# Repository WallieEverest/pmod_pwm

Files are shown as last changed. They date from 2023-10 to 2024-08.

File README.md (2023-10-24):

# Overview

This circuit is a PWM audio filter for the TT04 ChipTune project.
ChipTune replicates the Audio Processing Unit (APU) of vintage video games.
Separate PWM outputs are provided for each sound engine, allowing NES game music to be externally mixed into stereo or surround sound.
Resistor values will be tailored for balancing channel volume.

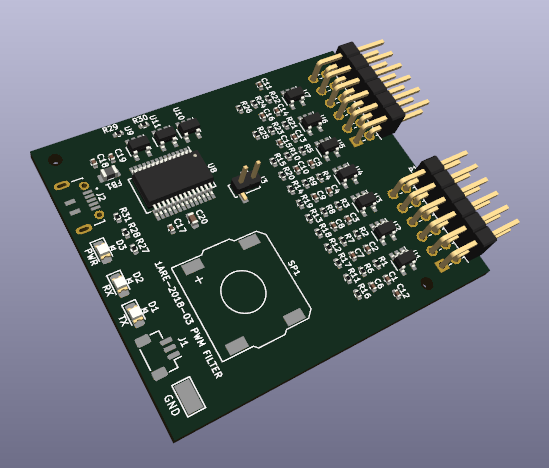
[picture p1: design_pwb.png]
Top Level Drawing


The primary interface is PMOD connectors to the TT04 Breakout Board. Final layout is pending assignment of all three PMOD connectors.

Based on data from:
- https://github.com/WallieEverest/tt04

## Interface

- UI_IN PMOD
- UO_OUT PMOD
- UIO PMOD (unused)
- USB-B for serial UART control of the Tiny Tapeout project
- JST 3-pin connector for low-level stereo preamp
- Onboard speaker for demonstrations

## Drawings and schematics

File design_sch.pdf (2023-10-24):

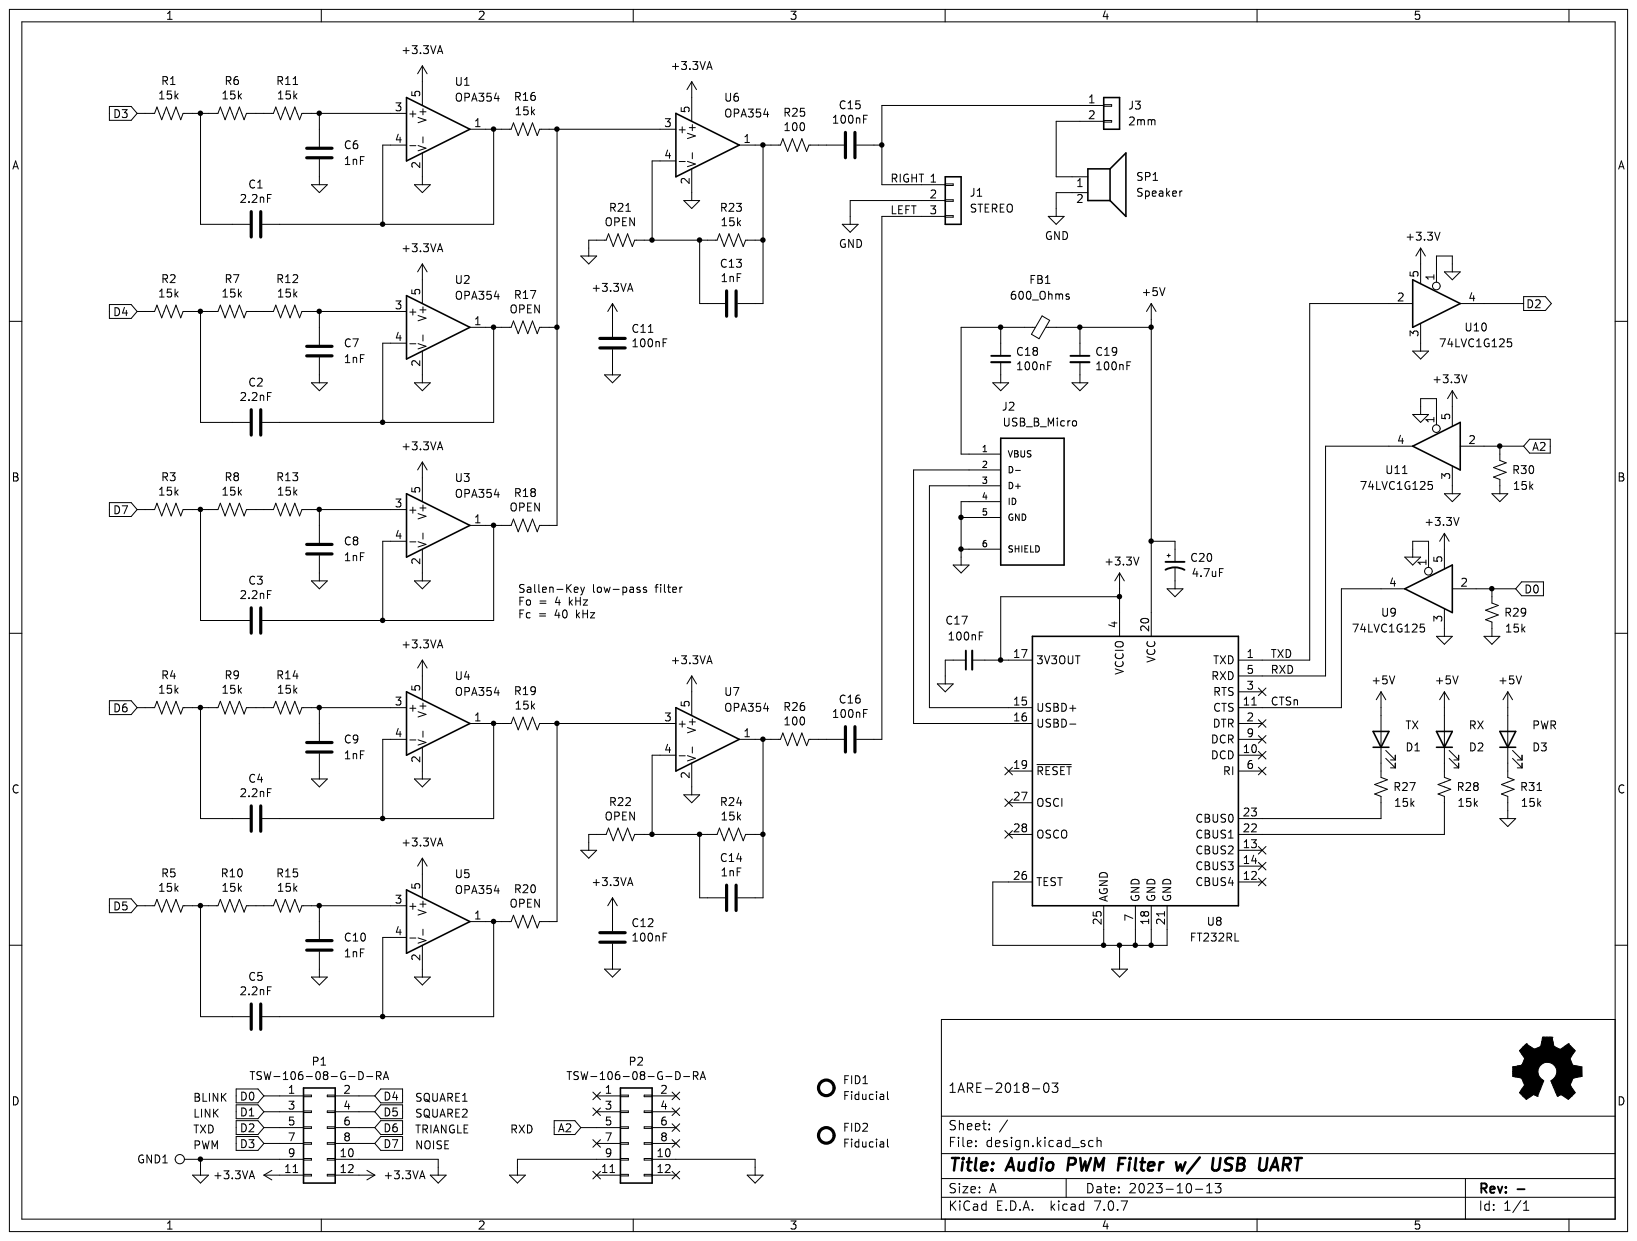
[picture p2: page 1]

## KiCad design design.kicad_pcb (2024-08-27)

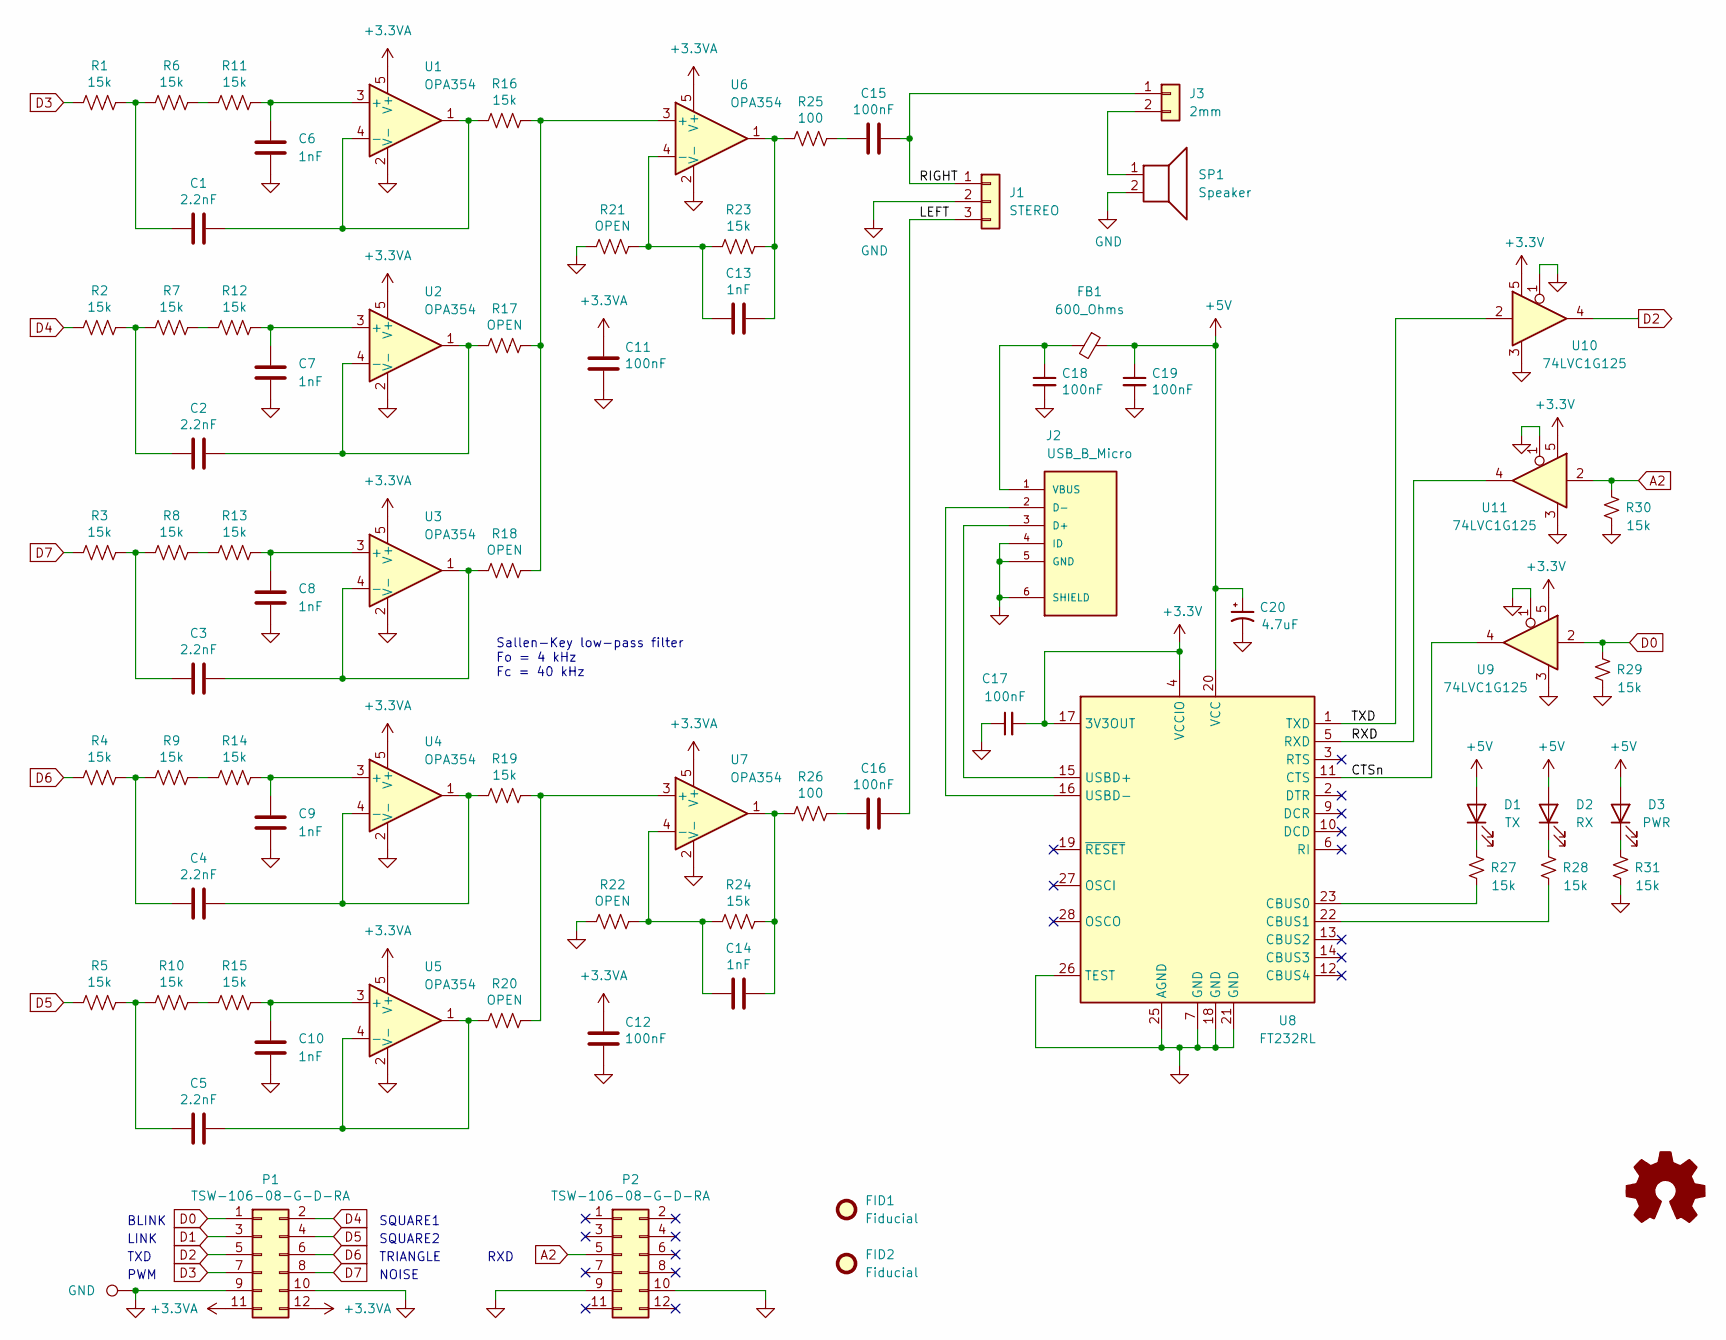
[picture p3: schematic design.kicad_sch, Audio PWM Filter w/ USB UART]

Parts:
C1, C2, C3, C4, C5: 2.2nF; C_0402_1005Metric; LCSC C913886
C6, C7, C8, C9, C10, C13, C14: 1nF; C_0402_1005Metric; LCSC C1523
C11, C12, C15, C16, C17, C18, C19: 100nF; C_0402_1005Metric; LCSC C1525
C20: 4.7uF; C_0603_1608Metric; LCSC C19666
D1: TX; LED_0805_2012Metric_Castellated; LCSC C2297
D2: RX; LED_0805_2012Metric_Castellated; LCSC C2297
D3: PWR; LED_0805_2012Metric_Castellated; LCSC C2297
FB1: 600_Ohms; L_0805_2012Metric; LCSC C1017
FID1, FID2: Fiducial; Fiducial_0.75mm_Mask1.5mm; LCSC None
J1: STEREO; JST_SH_BM03B-SRSS-TB_1x03-1MP_P1.00mm_Vertical; LCSC C160389
J2: USB_B_Micro; SHOUHAN_MICROXNJ; LCSC C404969
J3: 2mm; PinHeader_1x02_P2.00mm_Vertical_SMD_Pin1Left; LCSC C917549
P1, P2: TSW-106-08-G-D-RA; PinHeader_2x06_PMOD; LCSC C706887
R1, R2, R3, R4, R5, R6, R7, R8, R9, R10, R11, R12, R13, R14, R15, R16, R19, R23, R24, R27, R28, R29, R30, R31: 15k; R_0402_1005Metric; LCSC C25756
R17, R18, R20, R21, R22: OPEN; R_0402_1005Metric; LCSC C26083
R25, R26: 100; R_0402_1005Metric; LCSC C25076
SP1: Speaker; speaker_fs_1340; LCSC C482342
TP1: GND; TestPoint_Keystone_5019_Minature; LCSC C5199800
U1, U2, U3, U4, U5, U6, U7: OPA354; SOT-23-5_OPA; LCSC C36384
U8: FT232RL; SSOP-28_5.3x10.2mm_P0.65mm; LCSC C8690
U9, U10, U11: 74LVC1G125; SOT-23-5; LCSC C23654

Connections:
+3.3VA: C11.1, C12.1, P1.11, P1.12, U1.5 (V+), U2.5 (V+), U3.5 (V+), U4.5 (V+), U5.5 (V+), U6.5 (V+), U7.5 (V+)
+3V3: C17.2, U8.4 (VCCIO), U8.17 (3V3OUT), U9.5 (VCC), U10.5 (VCC), U11.5 (VCC)
+5V: C19.1, C20.1, D1.2 (A), D2.2 (A), D3.2 (A), FB1.1, U8.20 (VCC)
/CTSn: U8.11 (CTS), U9.4
/LEFT: C16.1, J1.3
/RIGHT: C15.1, J1.1, J3.1
/RXD: U8.5 (RXD), U11.4
/TXD: U8.1 (TXD), U10.2
A2: P2.5, R30.2, U11.2
D0: P1.1, R29.2, U9.2
D1: P1.3
D2: P1.5, U10.4
D3: P1.7, R1.2
D4: P1.2, R2.2
D5: P1.4, R5.2
D6: P1.6, R4.2
D7: P1.8, R3.2
GND: C6.2, C7.2, C8.2, C9.2, C10.2, C11.2, C12.2, C17.1, C18.2, C19.2, C20.2, J1.2, J2.4 (ID), J2.5 (GND), J2.6 (SHIELD), P1.9, P1.10, P2.9, P2.10, R21.2, R22.2, R29.1, R30.1, R31.1, SP1.2, TP1.1, U1.2 (V-), U2.2 (V-), U3.2 (V-), U4.2 (V-), U5.2 (V-), U6.2 (V-), U7.2 (V-), U8.7 (GND), U8.18 (GND), U8.21 (GND), U8.25 (AGND), U8.26 (TEST), U9.1, U9.3 (GND), U10.1, U10.3 (GND), U11.1, U11.3 (GND)
unnamed: C1.2, R1.1, R6.2
unnamed: C2.2, R2.1, R7.2
unnamed: C3.2, R3.1, R8.2
unnamed: C4.2, R4.1, R9.2
unnamed: C5.2, R5.1, R10.2
unnamed: C13.1, R23.1, R25.2, U6.1
unnamed: C14.1, R24.1, R26.2, U7.1
unnamed: C15.2, R25.1
unnamed: C16.2, R26.1
unnamed: D1.1 (K), R27.2
unnamed: D2.1 (K), R28.2
unnamed: D3.1 (K), R31.2
unnamed: J2.3 (D+), U8.15 (USBD+)
unnamed: J2.2 (D-), U8.16 (USBD-)
unnamed: C18.1, FB1.2, J2.1 (VBUS)
unnamed: J3.2, SP1.1
unnamed: R10.1, R15.2
unnamed: R6.1, R11.2
unnamed: R7.1, R12.2
unnamed: R8.1, R13.2
unnamed: R9.1, R14.2
unnamed: C6.1, R11.1, U1.3 (+)
unnamed: C1.1, R16.2, U1.1, U1.4 (-)
unnamed: C7.1, R12.1, U2.3 (+)
unnamed: C2.1, R17.2, U2.1, U2.4 (-)
unnamed: C8.1, R13.1, U3.3 (+)
unnamed: C3.1, R18.2, U3.1, U3.4 (-)
unnamed: C9.1, R14.1, U4.3 (+)
unnamed: C4.1, R19.2, U4.1, U4.4 (-)
unnamed: C10.1, R15.1, U5.3 (+)
unnamed: C5.1, R20.2, U5.1, U5.4 (-)
unnamed: R16.1, R17.1, R18.1, U6.3 (+)
unnamed: C13.2, R21.1, R23.2, U6.4 (-)
unnamed: R19.1, R20.1, U7.3 (+)
unnamed: C14.2, R22.1, R24.2, U7.4 (-)
unnamed: R27.1, U8.23 (CBUS0)
unnamed: R28.1, U8.22 (CBUS1)

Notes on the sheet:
NOISE
LINK
Sallen-Key low-pass filter Fo = 4 kHz Fc = 40 kHz
TRIANGLE
RXD
BLINK
SQUARE1
PWM
TXD
SQUARE2

Board: 4 copper layers, 75 parts (0 on the bottom side), 54 nets, no tracks yet.
